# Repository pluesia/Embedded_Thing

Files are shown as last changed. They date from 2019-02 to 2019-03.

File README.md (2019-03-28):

# Mini Audio Spectrum

A tiny embedded system that allows to provide simple analysis of an audio signal, connected by a jack.

# Introduction
This project belongs to the course Embedded System Design (E7020E) of the 
LTU.

The repository contains all hardware blueprints, and the sources for building
a Spectometre with a STM32F4 microcontroller. The language used have been cargo.
The main purpose is to show all the sound frecuencies of a song in real time.
The audio input is given with a 3,5mm jack, and the output is shown in a 
LED 8x8 matrix, displaying the intensity of each band of frecuency.

# Authors
William Lindell (linwil-5@student.ltu.se)

Pablo Luesia (pablue-8@student.ltu.se)

# Build
It is neccesary to have stlink, openocd and cargo installed.
For building the code, it is necesary to go inside the cloned
folder, and execute:

```shell
cargo build --bin mini_audio_spectrum --features "hal rtfm"
````

The debug output can be done with ITM

# Work done
1. Hardware schematics and layout
2. Real board mount
3. Reset and reboot buttons 
4. Implemented in the code:
* PWM working with the TIM1 of the STM32F4 for the LED intensity
* ADC conversion working with interrupts for reading the audio input
* UART for showing the results for depuration

# Future work
Program the PCB with the binaries generated:
* PWM for modulating the LED intensity
* Generate frecuency extractor for ADC input
* Showing results in the LED matrix
* Use UART for configure the LED intensity
 
# Grades
## Grade 3 
 Sampling and show a simple interpretation of the audio signal.  
## Grade 4
 Understand and implement the fourier transform algorithm for the audio input.  
## Grade 5
 Add different modes of the display and the audio.

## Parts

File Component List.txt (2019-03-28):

Shopping list
-------------------

Description					Amount		Elfa nr		Farnell nr	Digikey nr	SEK

61300611121 - Pin header Male 6 Single		3		300-24-526					2,88
https://www.elfa.se/en/pin-header-male-single-row-straight-without-shroud-wuerth-elektronik-61300611121/p/30024526

RND 205-00647 - Pin Header Female 7		2		300-93-667					9,25
https://www.elfa.se/en/pin-header-female-rnd-connect-rnd-205-00647/p/30093667?queryFromSuggest=true

RND 135-00038 - LED Grön 5 mm T-3 1/4		64		301-00-035					1,50
https://www.elfa.se/sv/led-groen-mm-rnd-components-rnd-135-00038/p/30100035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

Shift register 8 bit out latch			2		300-23-063					5,14
https://www.elfa.se/sv/74595-bit-shift-register-with-output-latches-pdip-16-texas-instruments-sn74hc595n/p/30023063

Audio Jack plug PJ-211				1		142-70-221					5,96
https://www.elfa.se/en/jack-panel-socket-nickel-plated-2p-zhejiang-zhengguang-pj-211/p/14270221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

Electrolitic Capacitor 10 µF			2		167-30-974					3,29
https://www.elfa.se/en/smd-electrolytic-capacitor-10-uf-16-vdc-rubycon-16sev10m4x5/p/16730974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

8 MHz Crystal Quartz				1		301-31-269					4,86
https://www.elfa.se/en/quartz-smd-8mhz-30-ppm-iqd-lfxtal011301/p/30131269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

LM1117IMPX					1		300-19-194					11,12
https://www.elfa.se/en/ldo-voltage-regulator-800-ma-sot-223-texas-instruments-lm1117impx-adj-nopb/p/30019194

Red button					1		135-66-546					1,01
https://www.elfa.se/en/print-key-50-ma-12-vdc-te-connectivity-1825910/p/13566546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

Black tall button				1		135-66-549					0,9063
https://www.elfa.se/en/print-key-50-ma-12-vdc-te-connectivity-1825910/p/13566549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

STM32F401RET6 -  ARM MCU			1				2432108				65,98 
https://se.farnell.com/stmicroelectronics/stm32f401ret6/mcu-32-bit-cortex-m4-84mhz-lqfp/dp/2432108

RND 205-00861 - Mini USB Connector		1		301-12-363					4,96
https://www.elfa.se/en/mini-usb-connector-smt-poles-rnd-connect-rnd-205-00861/p/30112363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

Resistors used are from E12s

220 Ohm						8
10k Ohm						6
1k Ohm						2
2.2k Ohm					1
1.8k Ohm					1
8.2k Ohm					1

Resistors used are from 0805s

0.1uF						2
100nF						11
10uF						2
4.7uF						2
1uF						1
18pF						2

Total Things = 24

All of them should be listed at Column Mini Audio Spectrum now

https://docs.google.com/spreadsheets/d/1h9H-vIpOehOyXNSAo5Ac9nzNG-_aQqIoclw2sk2FT1k/edit#gid=789537178

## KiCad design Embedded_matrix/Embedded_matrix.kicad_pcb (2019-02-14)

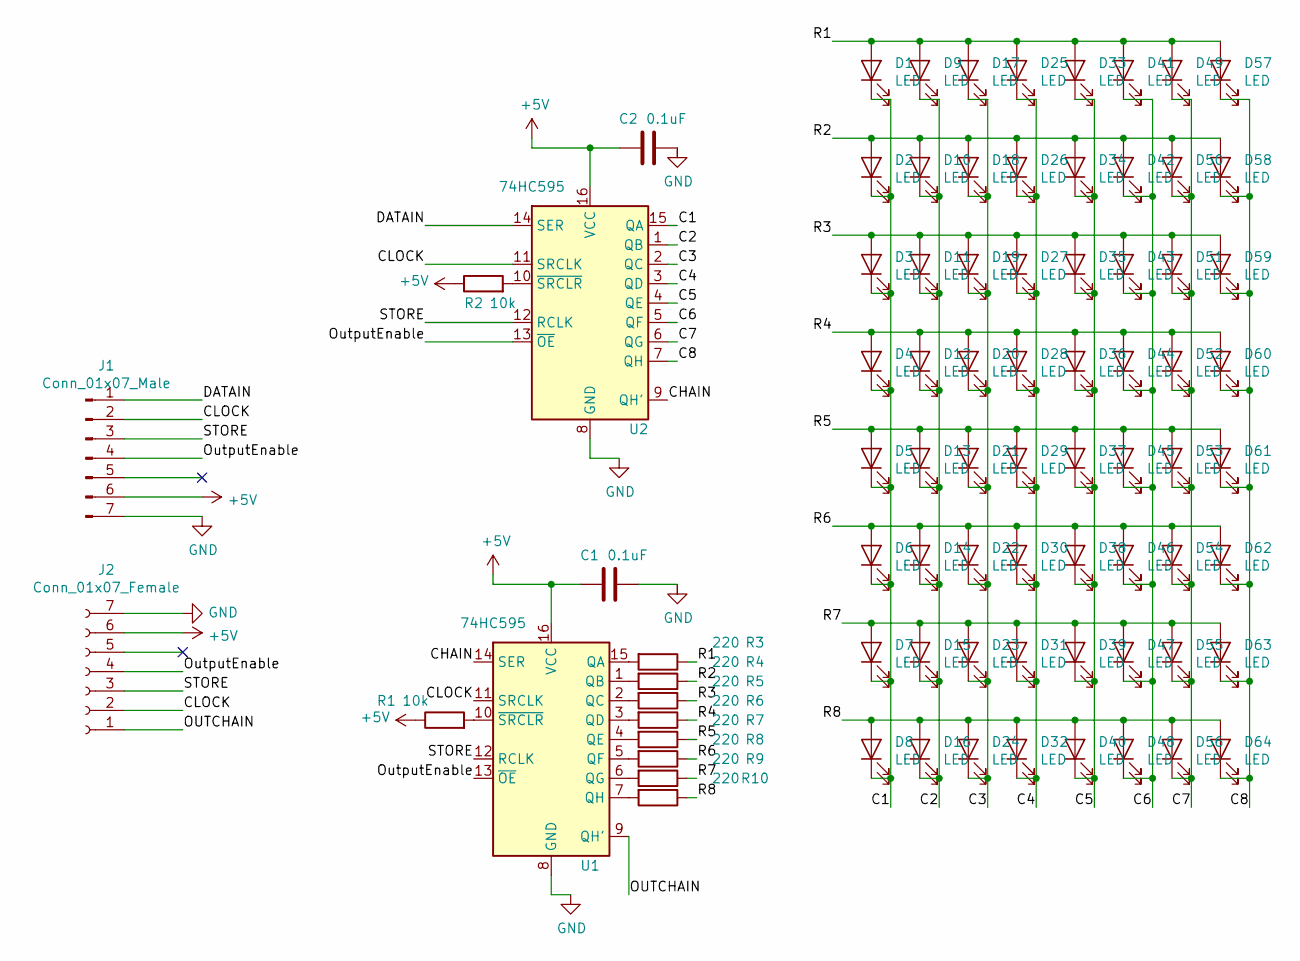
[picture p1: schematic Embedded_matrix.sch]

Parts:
C1, C2: 0.1uF; C_0805_2012Metric
D1, D2, D3, D4, D5, D6, D7, D8, D9, D10, D11, D12, D13, D14, D15, D16, D17, D18, D19, D20, D21, D22, D23, D24, D25, D26, D27, D28, D29, D30, D31, D32, D33, D34, D35, D36, D37, D38, D39, D40, D41, D42, D43, D44, D45, D46, D47, D48, D49, D50, D51, D52, D53, D54, D55, D56, D57, D58, D59, D60, D61, D62, D63, D64: LED; LED_D5.0mm
J1: Conn_01x07_Male; PinHeader_1x07_P2.54mm_Vertical
J2: Conn_01x07_Female; PinHeader_1x07_P2.54mm_Vertical
R1, R2: 10k; R_0805_2012Metric_Pad1.15x1.40mm_HandSolder
R3, R4, R5, R6, R7, R8, R9, R10: 220; R_0805_2012Metric_Pad1.15x1.40mm_HandSolder
U1, U2: 74HC595; DIP-16_W7.62mm_Socket

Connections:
+5V: C1.1, C2.1, J1.6, J2.6, R1.1, R2.1, U1.16 (VCC), U2.16 (VCC)
/C1: D1.1 (K), D2.1 (K), D3.1 (K), D4.1 (K), D5.1 (K), D6.1 (K), D7.1 (K), D8.1 (K), U2.15 (QA)
/C2: D9.1 (K), D10.1 (K), D11.1 (K), D12.1 (K), D13.1 (K), D14.1 (K), D15.1 (K), D16.1 (K), U2.1 (QB)
/C3: D17.1 (K), D18.1 (K), D19.1 (K), D20.1 (K), D21.1 (K), D22.1 (K), D23.1 (K), D24.1 (K), U2.2 (QC)
/C4: D25.1 (K), D26.1 (K), D27.1 (K), D28.1 (K), D29.1 (K), D30.1 (K), D31.1 (K), D32.1 (K), U2.3 (QD)
/C5: D33.1 (K), D34.1 (K), D35.1 (K), D36.1 (K), D37.1 (K), D38.1 (K), D39.1 (K), D40.1 (K), U2.4 (QE)
/C6: D41.1 (K), D42.1 (K), D43.1 (K), D44.1 (K), D45.1 (K), D46.1 (K), D47.1 (K), D48.1 (K), U2.5 (QF)
/C7: D49.1 (K), D50.1 (K), D51.1 (K), D52.1 (K), D53.1 (K), D54.1 (K), D55.1 (K), D56.1 (K), U2.6 (QG)
/C8: D57.1 (K), D58.1 (K), D59.1 (K), D60.1 (K), D61.1 (K), D62.1 (K), D63.1 (K), D64.1 (K), U2.7 (QH)
/CHAIN: U1.14 (SER), U2.9 (QH')
/CLOCK: J1.2, J2.2, U1.11 (SRCLK), U2.11 (SRCLK)
/DATAIN: J1.1, U2.14 (SER)
/OUTCHAIN: J2.1, U1.9 (QH')
/OutputEnable: J1.4, J2.4, U1.13 (~OE), U2.13 (~OE)
/R1: D1.2 (A), D9.2 (A), D17.2 (A), D25.2 (A), D33.2 (A), D41.2 (A), D49.2 (A), D57.2 (A), R3.1
/R2: D2.2 (A), D10.2 (A), D18.2 (A), D26.2 (A), D34.2 (A), D42.2 (A), D50.2 (A), D58.2 (A), R4.1
/R3: D3.2 (A), D11.2 (A), D19.2 (A), D27.2 (A), D35.2 (A), D43.2 (A), D51.2 (A), D59.2 (A), R5.1
/R4: D4.2 (A), D12.2 (A), D20.2 (A), D28.2 (A), D36.2 (A), D44.2 (A), D52.2 (A), D60.2 (A), R6.1
/R5: D5.2 (A), D13.2 (A), D21.2 (A), D29.2 (A), D37.2 (A), D45.2 (A), D53.2 (A), D61.2 (A), R7.1
/R6: D6.2 (A), D14.2 (A), D22.2 (A), D30.2 (A), D38.2 (A), D46.2 (A), D54.2 (A), D62.2 (A), R8.1
/R7: D7.2 (A), D15.2 (A), D23.2 (A), D31.2 (A), D39.2 (A), D47.2 (A), D55.2 (A), D63.2 (A), R9.1
/R8: D8.2 (A), D16.2 (A), D24.2 (A), D32.2 (A), D40.2 (A), D48.2 (A), D56.2 (A), D64.2 (A), R10.1
/STORE: J1.3, J2.3, U1.12 (RCLK), U2.12 (RCLK)
GND: C1.2, C2.2, J1.7, J2.7, U1.8 (GND), U2.8 (GND)
unnamed: R1.2, U1.10 (~SRCLR)
unnamed: R2.2, U2.10 (~SRCLR)
unnamed: R3.2, U1.15 (QA)
unnamed: R4.2, U1.1 (QB)
unnamed: R5.2, U1.2 (QC)
unnamed: R6.2, U1.3 (QD)
unnamed: R7.2, U1.4 (QE)
unnamed: R8.2, U1.5 (QF)
unnamed: R9.2, U1.6 (QG)
unnamed: R10.2, U1.7 (QH)

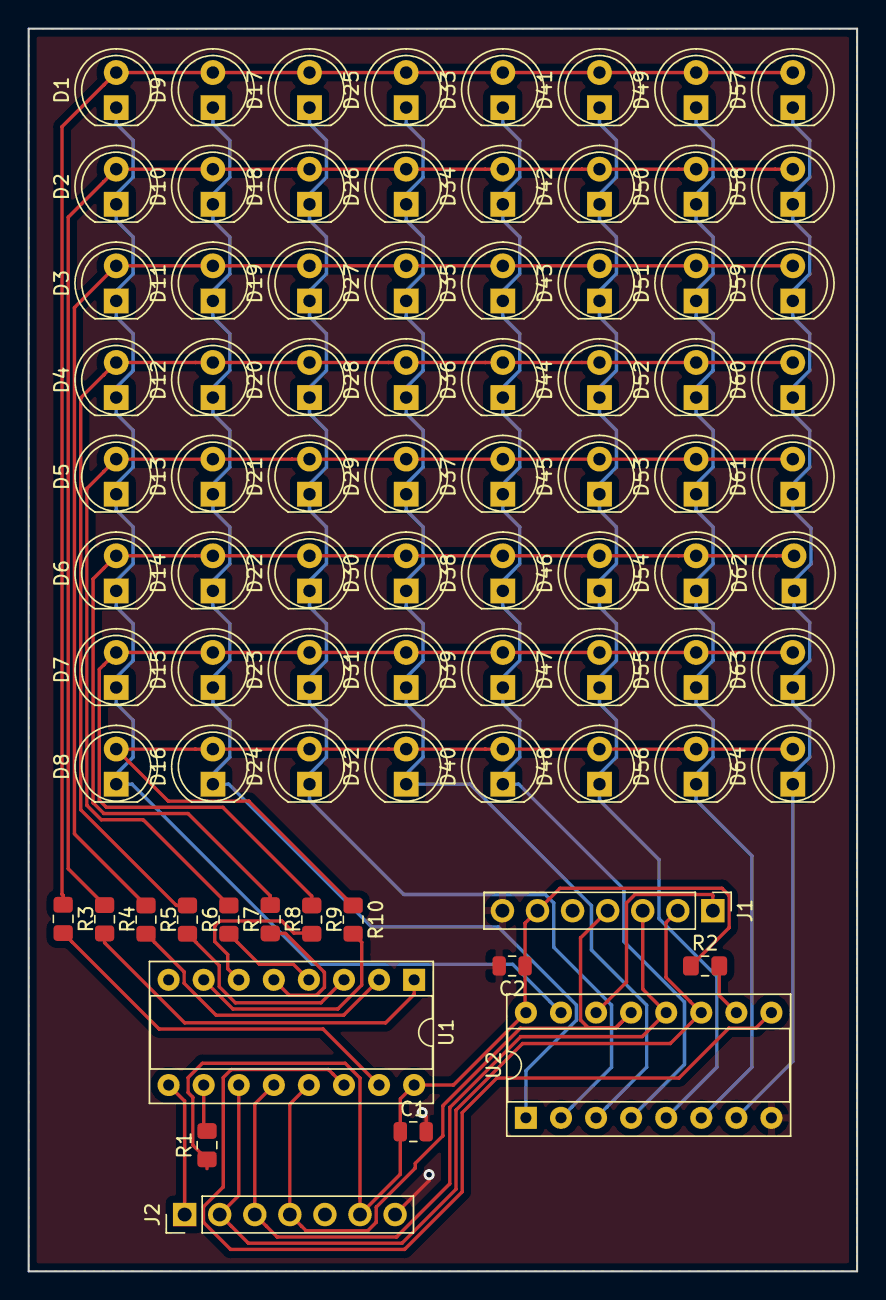
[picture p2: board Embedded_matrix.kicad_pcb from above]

Board: 2 copper layers, 60.0 x 90.0 mm, 80 parts (0 on the bottom side), 34 nets.

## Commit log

2019-02-06 Adding layouts
    [Embedded_Spectrum.kicad_pcb, Embedded_Spectrum.sch]
2019-02-07 Created jack footprint
2019-02-08 added 7x5 footprint matrix
    Here is the footprint of 7x5 matrix, hope it is right
2019-02-12 Added jack
    [Embedded_Spectrum.sch]
2019-02-13 Schematic for led matrix
    here is the schematic
    [Embedded_matrix.kicad_pcb, Embedded_matrix.sch]
2019-02-13 Added buttons
    [Embedded_Spectrum.sch]
2019-02-13 Half of the control PCB blueprints added
    [Embedded_Spectrum.sch]
2019-02-13 RIP matrix for now lets use leds
    updated
    [Embedded_matrix.sch]
2019-02-13 Assigned PCB footprints
    Might be checked again to see they are in left in stock on sites
    led -> https://www.elfa.se/sv/led-groen-mm-rnd-components-rnd-135-00038/p/30100035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
    -> capaictor -> https://www.elfa.se/en/ceramic-disk-capacitor-100-nf-50-vdc-mm-hitano-sf1h104z-l515b/p/16565659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
    pin female --> https://www.elfa.se/en/pin-header-female-rnd-connect-rnd-205-00647/p/30093667?queryFromSuggest=true
    pin ma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
    [Embedded_matrix.sch]
2019-02-14 Finished control PCB. Generated greb files
    [Embedded_Spectrum-B.Cu.gbr, Embedded_Spectrum-B.Mask.gbr, Embedded_Spectrum-Edge.Cuts.gbr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]
2019-02-14 PCB made, might check, then gerber if not..
    Here is the PCB for the matrix pcb with 8x8 leds, the input pins and output pins looks the same but one will be with socket. Both female and male connector pins are the same according to the seller /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
    Pin size for male connector = Pin size for femlae connector.
    And the cupper traces could probably been better made x)
2019-02-14 Generated matrix gerber files
    [Embedded_matrix-B.Cu.gbr, Embedded_matrix-B.Mask.gbr, Embedded_matrix-Edge.Cuts.gbr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]
2019-03-28 Added Led intensity with uart
